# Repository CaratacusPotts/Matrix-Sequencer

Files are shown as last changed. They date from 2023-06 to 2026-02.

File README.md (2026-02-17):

# Matrix-Sequencer
**Stand Alone Midi Sequencer**, for immediate visual interaction with hardware synthesizers

## What
Midi sequencer designed to be easy to modify for beginners, and low cost to make.
Based on Arduino.

Operates in:
- Loop Mode
- Song Mode
- Conductor Mode

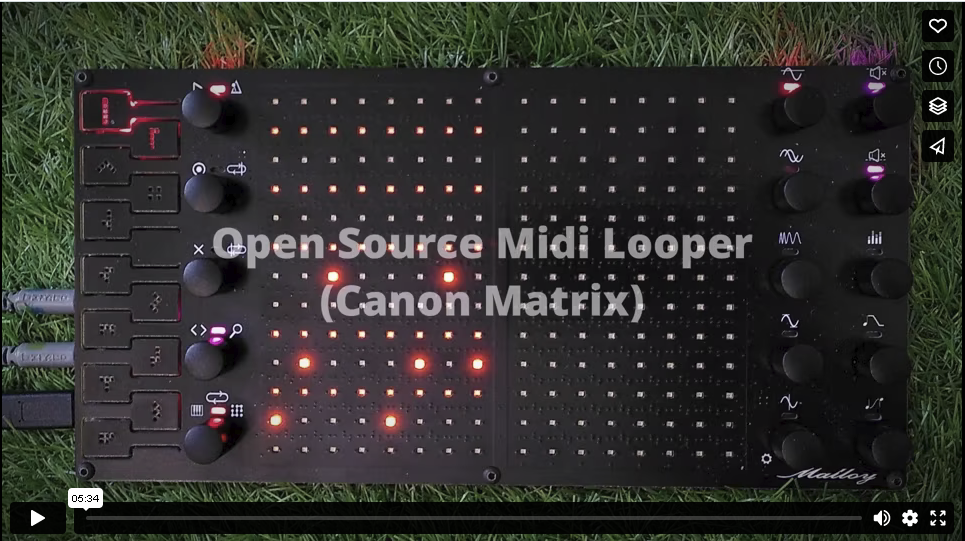
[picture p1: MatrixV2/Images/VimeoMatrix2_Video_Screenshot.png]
Video Thumbnail (https://www.youtube.com/watch?v=TjFpd8f3n0o)


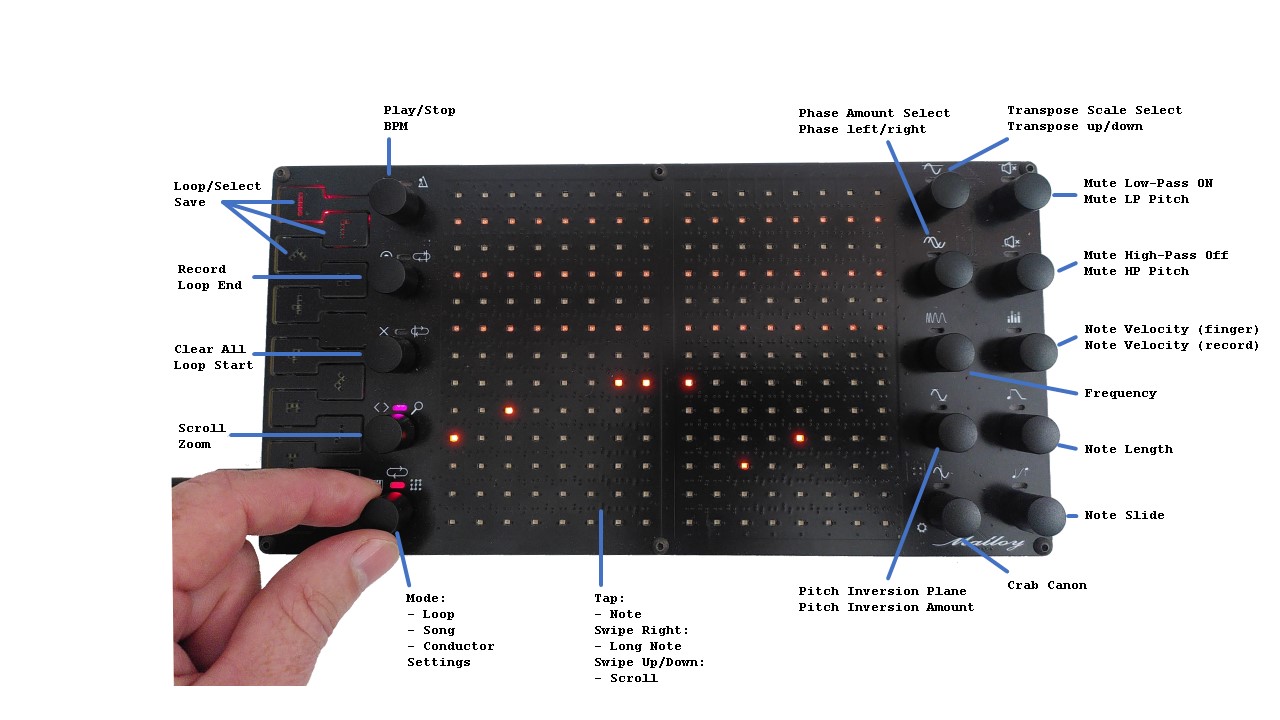
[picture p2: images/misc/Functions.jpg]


### Basic Functions (left row):
- Start/Stop: Play using internal clock or external midi clock
- BPM change using encoder
- Loop Start and End points via encoder
- Record:
  - Overtop: using Encoder button
  - On-Play: holding foot pedal, recording starts when first note played. Recording stops with foot off pedal. Automatically cuts loop to nearest beat, so loops nice.
- Clear notes (via encoder button)

### Canon and Note Functions (right rows):
- Transpose (to scale, on/off beat, via encoder or key input)
- Phase (by multiples of loop, by amount in steps)
- Frequency (compress note sequence in time, in fractions of current loop length)
- Mirror Notes Pitch (with a user defined mirror plane, reflect notes in pitch axis)
- Mirror Notes Loop (with a user defined mirror plane, reflect notes in time)
- Note Cutofff Filter (mute notes like a LPF or HPF)
- Note Velocity (use finger to draw note velocity or encoder)
- Note Duration (use encoder to increase or decrease all note lengths)

### Additional Features:
- 256 events (not bound by bars or specific steps)
- Polyphonic
- Intuitive scales

## [Specifications / Information Matrix V2 (encoder model)](MatrixV2/README.md)
## [Specifications / Information Matrix V1](MatrixV1/README.md)
## [Specifications / Informatoin Inline (simple midi looper)](Inline/README.md)

## Why
### Hardware synthesizer problem:

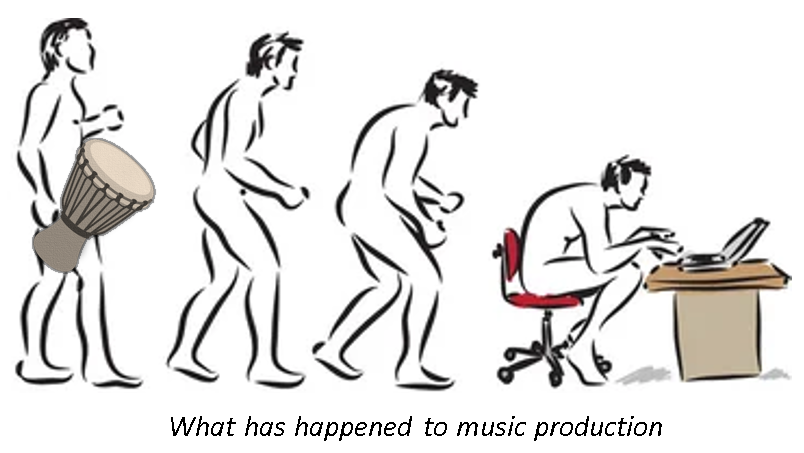
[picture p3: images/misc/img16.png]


Electronic music possesses both its greatest asset and its greatest drawback: the unparalleled flexibility it offers in sound creation. It's simple to purchase a laptop, load your favourite DAW software, and then to wake up, after you have nodded off to a loop running endlessly in your headphones. Perhaps you may get lucky, and a fortuitous accidental mouse click during your slumber may result in a masterpiece. However, it is more probable that your music will end up sounding sterile.

Hardware synthesizers currently provide immediacy, tangibility, reliability and lack of spontaneous OS updates, that PC's cannot provide.  But without expensive hardware, the only way to quickly layer sounds is to use built in key-holds playing standard arpeggios that steadily erode their beauty through endless repetition of the same up/down sequences.

Goal was to:
- make an interface that allows for quick note controller access, with immediate visual and tactile feedback - with a nod to the Reason Matrix
- Keep cost low.  There are solutions already that do similar things, but start at £650 upwards. 
- Enhance workflow and notation in areas that typically do not get attention, that have a meaningful impact of the quality of music, such as instant: 
  - Transposing in key
  - Phasing
  - High-pass and Low-pass velocity muting
  - Canon functions in key (Crab, Inversion, Reversing etc)
  - Hardware agnostic 303 style accents and glides
  - Velocity and length control
- Composer mode, allowing the user to play a midi keyboard, and to be able to select which fingers play which synthesizer (for example: left pinky plays bass, middle finger lead, first 3 fingers strings etc)
- Record mode, where it starts the recording only when you play, and stops the recording and automatically trims length when you remove you foot.  This allows seemless live looping.
- Loops that are not bound by 16,32 or 64 steps.  But is only bound by number of events.  In the current state, this is 255 events, over a 32bit length of steps (which at low tempo could be a 10 min loop)
- Scale not chosen by archaic and unrelatable names.  Notes (key) chosen by just selecting which white and black note you want it to stay on - yes, that simple.  (Does not currently handle option to change base notes if going up or down like in a some melodic minor scales - to be added) 
- Open source and easy to modify for non-programmers to allow people to add features and tweak to their setup.  I really tried to avoid the use of pointers, classes, libraries etc, as I wanted this to be software that anyone could modify - worts and all (I failed on the Midi Library - need remove this at some point)
- Fit into existing setups without changing anything (inline).
- Assemble at home with basic SMD tools, and a 3D printer.

## Contents of the repository

I have tried to include everything I created on this project.

Please note: There are some schematic errors which required minor board mods!!  I have not got around to updating the PCB files.  Please see notes in folders for each item.

Files are for:
- Matrix (second one - with encoders built in)
- Inline looper
- Inline controller
- Matrix (first one - with not encoders)

Each folder contains:
- PCB schematics
- PCB Kicad files
- Arduino Code
- Azoteq touch files
- CAD files (plastic)
- BOM (mostly mouser parts)

#### Numbering style is me having fun..  

We really need to move to a base-12 system.  So so much better.  This is my base-12 numbering, using the super cool Pentomino. See https://en.wikipedia.org/wiki/Pentomino  (thank you Arthur C Clake for enlightening me)

This is my sequence below.  Using the beauty of base 12, like in music there are those lovely 4x3's.  You can see the pattern repeating and growing in complexity (5 is a slight mod of one, 6 of 2 and so on.  9 slight mod of 5, 10 of 6 and so on).  Tried to not have the shapes the same as western numbers.

More info here: [PENTOMINO](Pentomino/INFORMATION.md)

I also wanted the first numbers to grow dimensionally 1 side, 2 side, 3 side (also shown as triangle), 4 side (Pentomino cross is shown as a negative, as it looks better - and makes a square :-) ). 
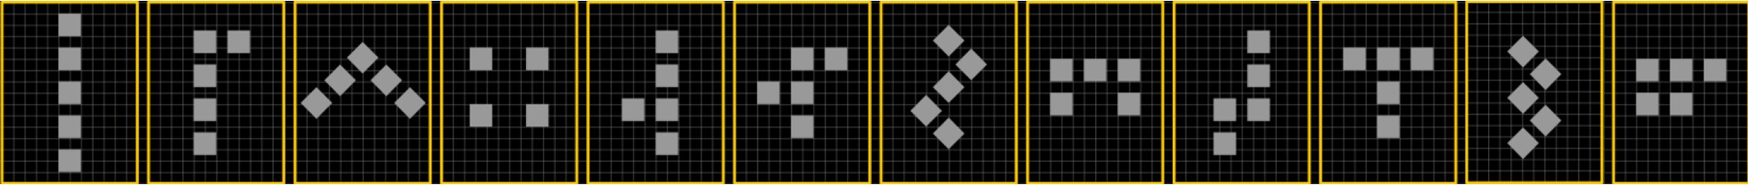
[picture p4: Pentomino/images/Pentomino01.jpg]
Pentomino01


## Photos

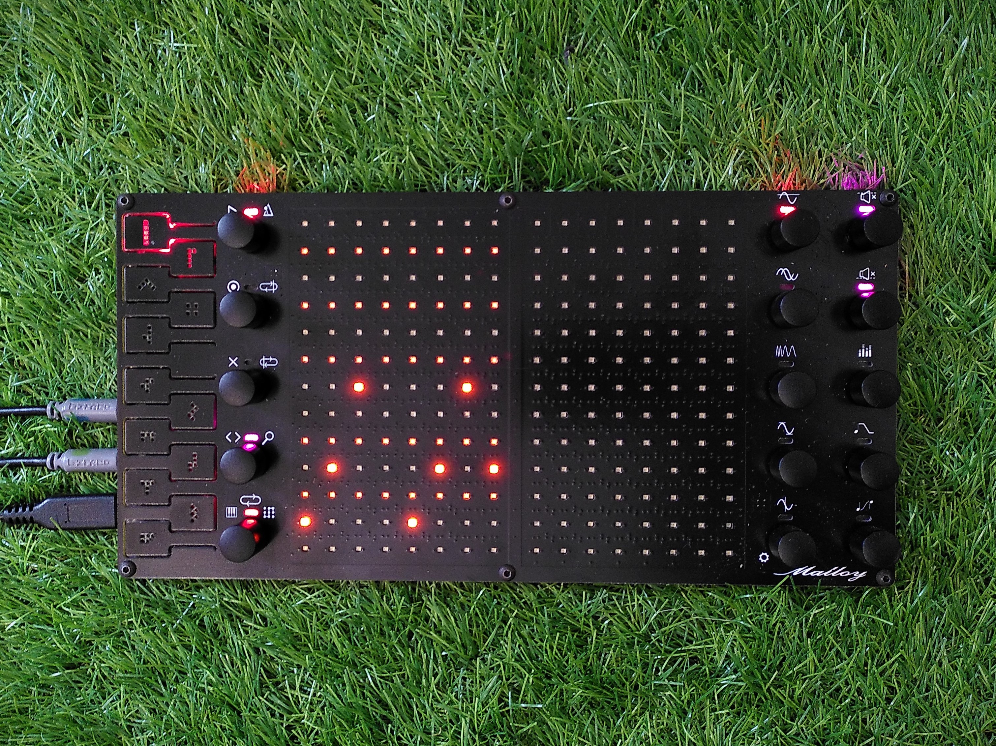
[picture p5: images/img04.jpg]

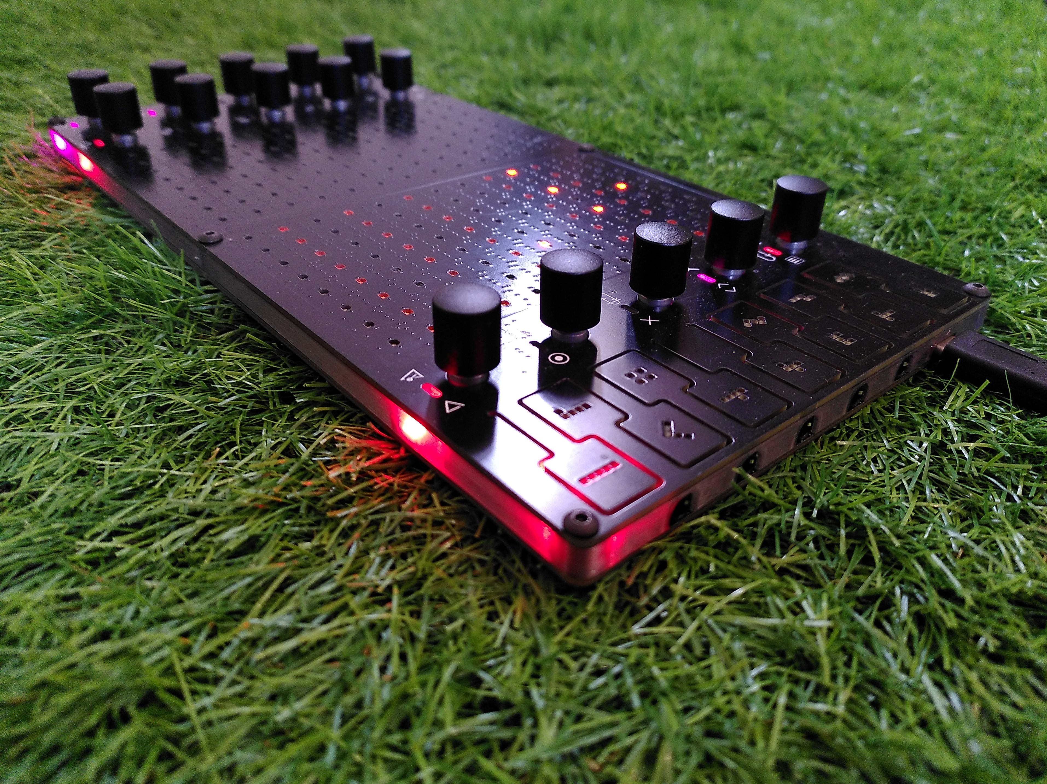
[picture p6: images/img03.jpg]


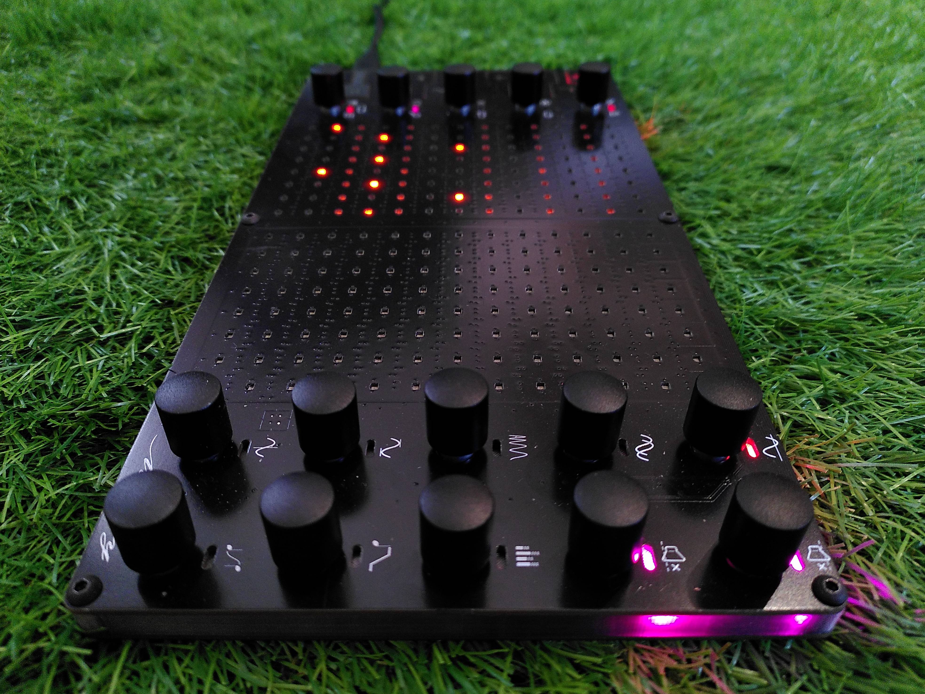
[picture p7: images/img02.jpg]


# Other Verions

## First Verison


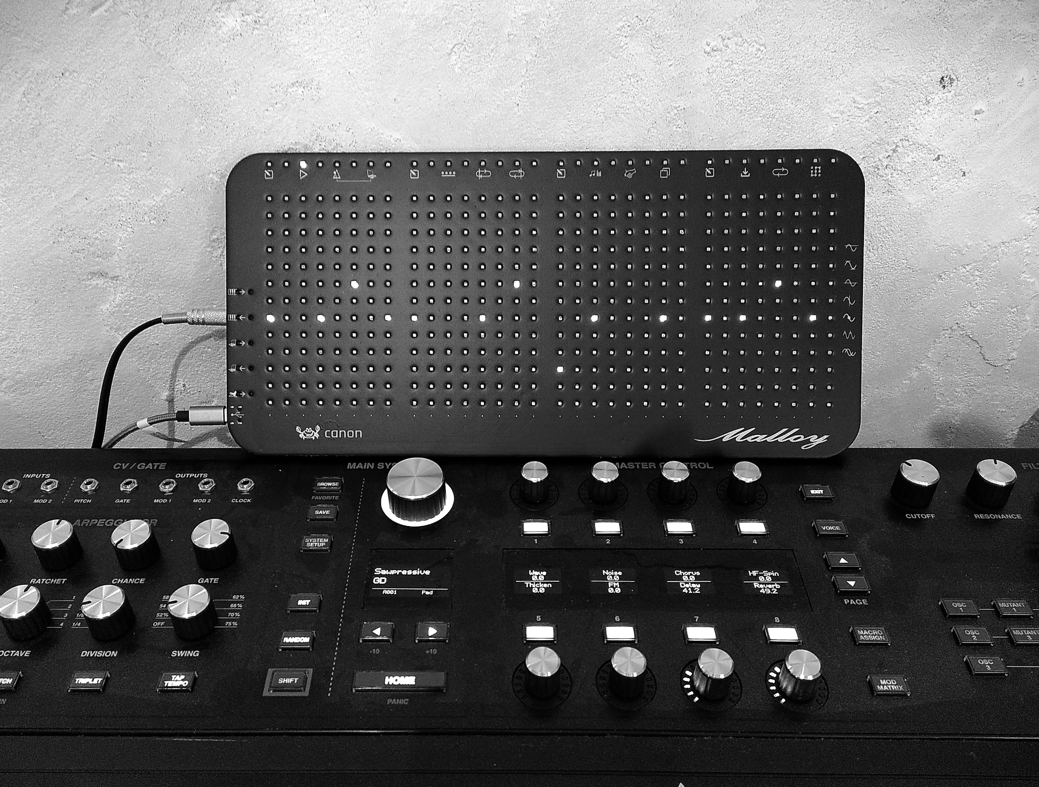
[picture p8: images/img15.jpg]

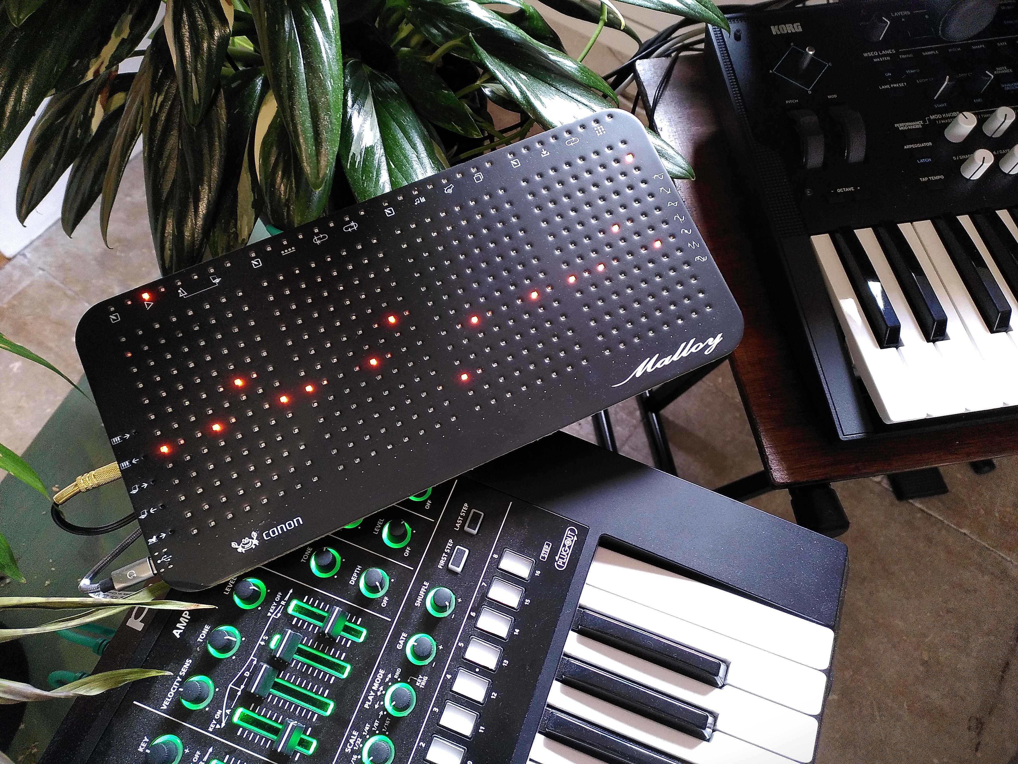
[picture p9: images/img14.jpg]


## Inline Midi 
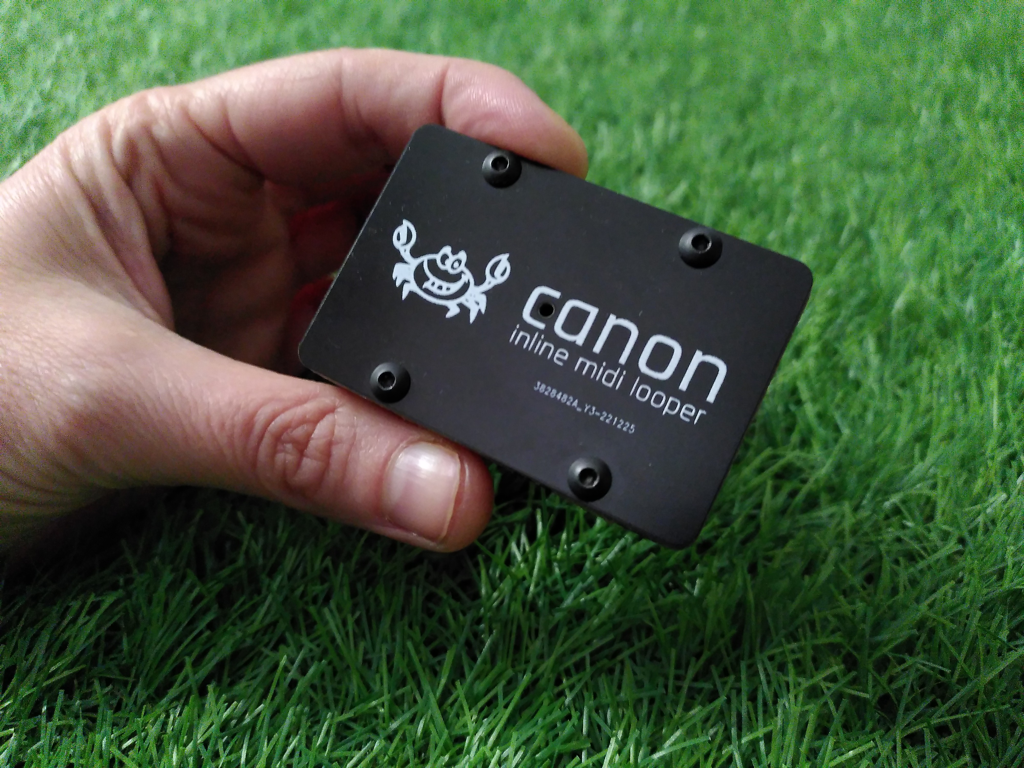
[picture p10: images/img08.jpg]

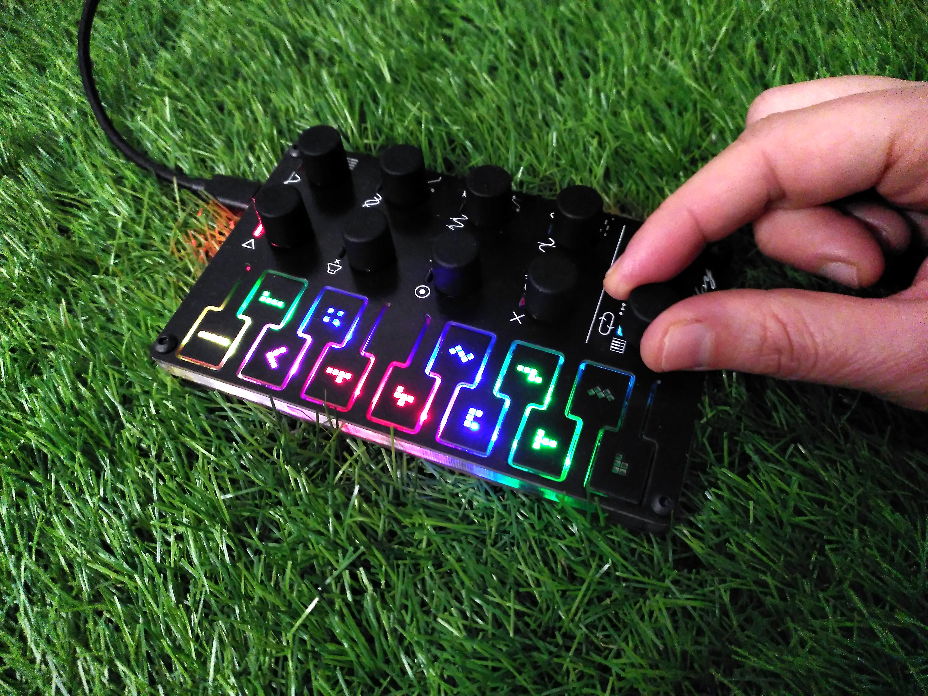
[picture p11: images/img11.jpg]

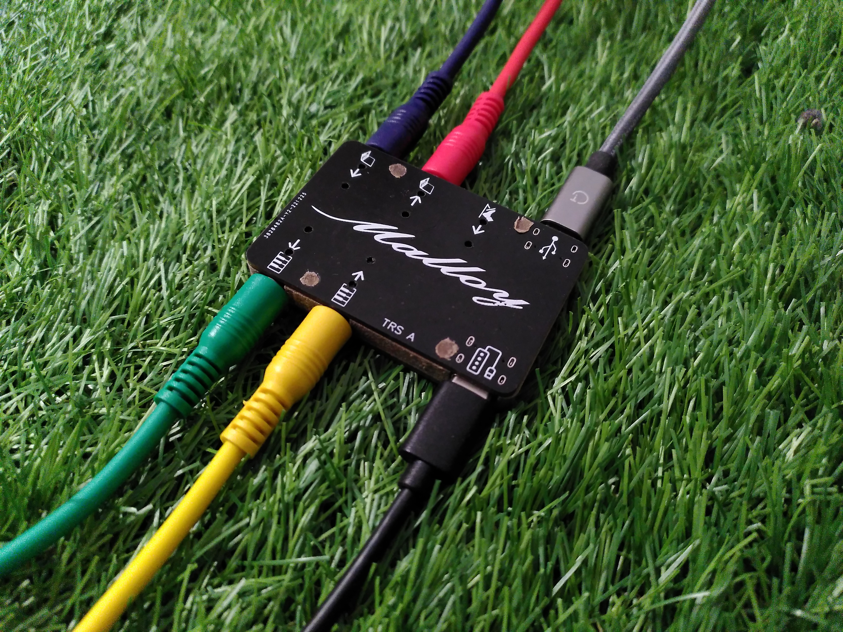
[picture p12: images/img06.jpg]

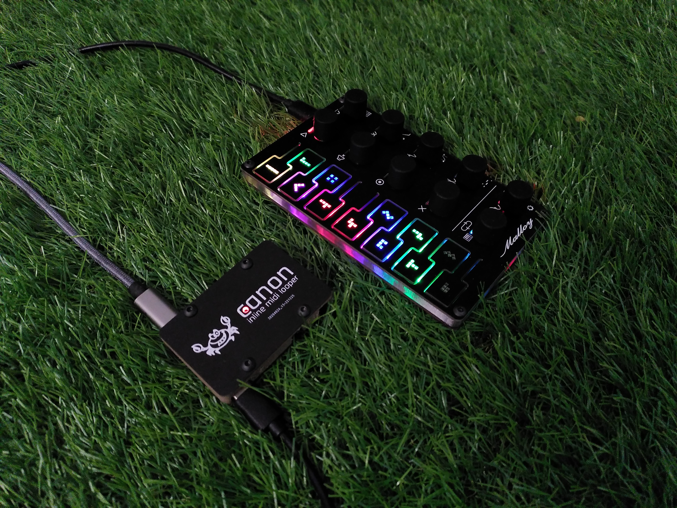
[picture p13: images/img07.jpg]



## Who
My name is Chris Malloy.  I developed the Hoverbike back in 2006.  For the last 10 years, my fantastic team and I have built a sucessful company that makes large heavy lift unmanned vehicles (company: Malloy Aeronautics www.malloyaeronautics.com )

I needed a break from that type of engineering, so whilst still helping the company, I have spent the last year finding time to work on this, and de-bug and have lots of fun playing on my gear.
If you want to listen to some very novice music made using this Matrix seqencer, see:
https://soundcloud.com/c-malloy

A Vimeo channel with a video of an earlier version of the Matrix
Version1 Sequencer (https://vimeo.com/770474252)

All the best

Chris

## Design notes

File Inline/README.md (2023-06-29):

## PLEASE NOTE:
This is a low TRL device, and as such, please see known issues below.

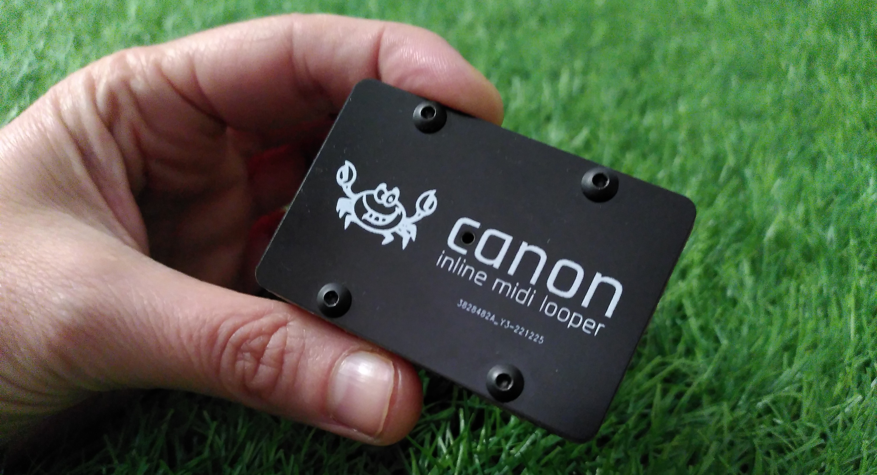
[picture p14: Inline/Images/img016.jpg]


## Overview
### Inputs and Outputs
- USB C to power and program
- USB C to connect to Controller
- 4x Midi TRS type A
  - Midi out to Synth
  - Midi in from Synth
  - Midi in from Computer/Master Clock
  - Midi out to computer/other
- 1x Trigger (3.5mm type) jack for pedal etc.

### Electronics
- Based on Adafruit ItsyBitsy MO Express https://www.adafruit.com/product/3727
- Processor: ATSAMD21 Cortex M0 processor running at 48 MHz
- External Memory: EEPROM 512k I2C
- 24 pin I/O Expander: PCAL6524HEAZ 
- Leds for indication: IN-PI55TATPRPGPB 
- Encoders, LDO power, Caps, Resistors etc

### Controls

- The controller works the same as the Matrix V2.
- This was an eariler version, that I used to experiment and debug the concept.
- THe Controller board needs some work, but the Inline Board (stand alone MIDI looper) is ready to go, and works quite well.

## Issues

### SCHEMATIC

### PCB

### CAD

### CODE

laylout
laylout
laylout
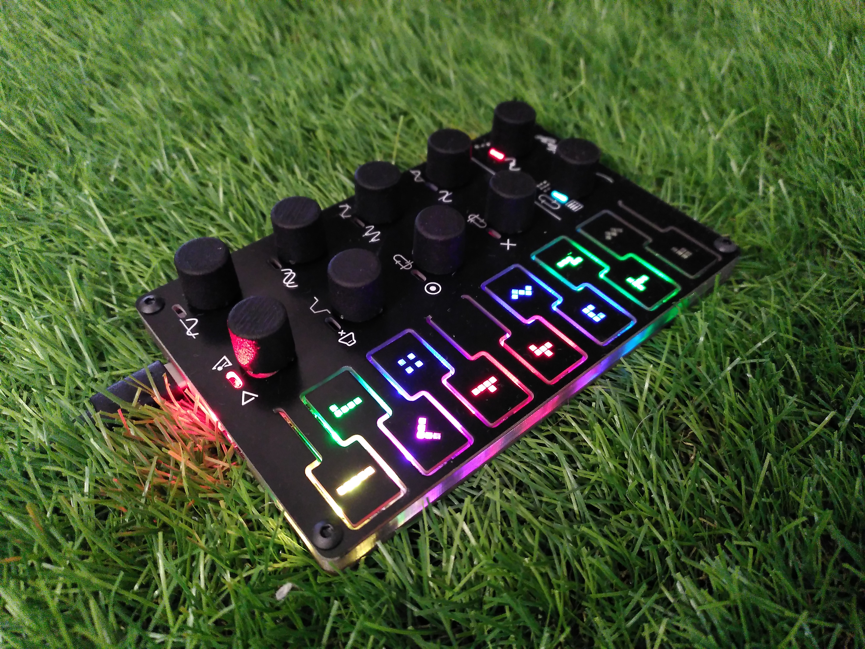
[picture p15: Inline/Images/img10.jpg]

laylout

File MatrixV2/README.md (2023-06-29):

## PLEASE NOTE:
This is a low TRL device, and as such, please see known issues below.

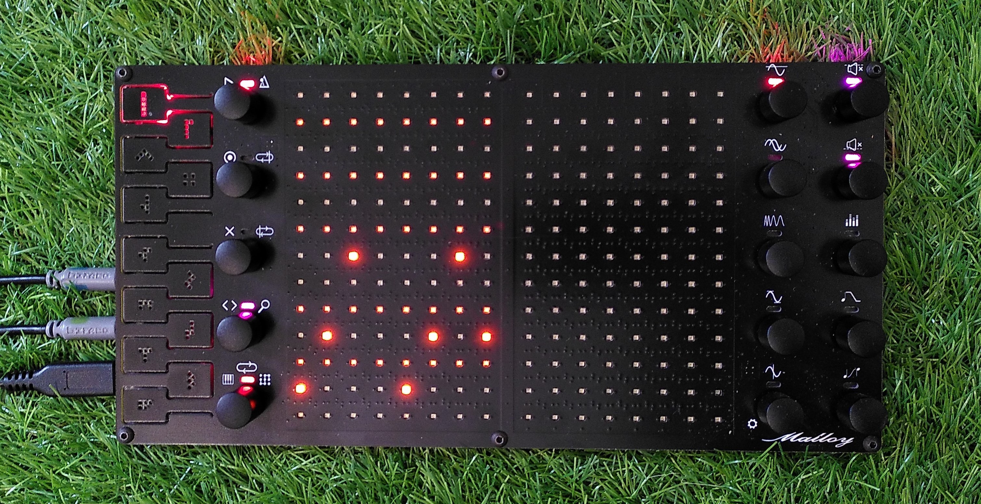
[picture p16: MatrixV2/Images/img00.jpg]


## Overview
### Inputs and Outputs
- USB C to power and program
- 4x Midi TRS type A
  - Midi out to Synth
  - Midi in from Synth
  - Midi in from Computer/Master Clock
  - Midi out to computer/other
- 1x Trigger (3.5mm type) jack for pedal etc.

### Electronics
- Based on Adafruit ItsyBitsy MO Express https://www.adafruit.com/product/3727
- Processor: ATSAMD21 Cortex M0 processor running at 48 MHz
- External Memory: EEPROM 512k I2C
- Touch: 2x Azoteq multitouch QS550 I2C
- 24 pin I/O Expander: 2x PCAL6524HEAZ 
- Led Latch: 2x CAT4016HV6G
- Leds for display: APTR3216SECK and RGB Leds for indication: IN-PI55TATPRPGPB 
- Encoders, LDO power, Caps, Resistors etc

### Controls

Buttons 1-12.  
- Used for saving (long press) loop
- Loading loop or song based on mode you are in (tap new number)
- Mute all notes (tap the same loop number).
- Also used to see scale, by holding the transpose button, you can select which notes you want the tranpose and other function to keep your pattern to.
- Play Notes
Encoders and Encoder Buttons (working down in columns - from left)
- Play/BPM
  - Click:  Start/Stop
  - Turn:  BPM
  - Click and Turn: Turn sync off/on
- Record/Loop End
  - Click: Record notes played in via midi, over top of current loop
  - Turn:  Adjust loop end point
- Clear/Loop Start
  - Click: Clear all notes
  - Turn: Adjust loop start point
- Scroll/Zoom
  - Turn: Scroll screen left/right
  - Press and Turn: Zoom in/out (by amount in steps-per-beat)
- Mode:
  - Turn: Left=Conductor Mode, Middle=Loop Mode, Right=Song Mode
    - Conductor Mode: See more information below
    - Loop Mode: Play loop continuously, based on internal BPM or external MIDI sync
    - Song Mode: See more information below
- Transpose:
  - Click: Active remote transpose.  This allows keyboard MIDI input to transpose note
  - Click and Hold: Set scale for tranpose, using number buttons (layed out as paino keys) or MIDI keyboard input.  
  - Turn: Transpose up/down
  - NOTE: Tranpose will try and shift notes onto the selected note only.
- Phase:
  - Click: Active phase.  This will phase shift the loop based on the number of times the loop has played
  - Click and Turn: Adjust the phase amount (negative or positive)
  - Turn: Manually phase shift notes
- Frequency
  - Turn: Change how fast the notes are played (*2 or /2 of current notes)
- Y-Mod Notes:
  - Turn: Reflect notes progressively about a defined axis
  - Click and Turn: Adjust where the reflection axis is (notes will be progressively reflected about this point)
- X-Mod Notes:
  - Turn: Reflect notes progressively about a defined axis
  - Click and Turn: Adjust where the reflection axis is (notes will be progressively reflected about this point)
- Mute LPF:
  - Click: Turn on.  All notes below threshold will play
  - Turn: Left sets threshold down in pitch.  Up goes up.
- Mute HPF:
  - Click: Turn on.  All notes above threshold will play
  - Turn: Left sets threshold down in pitch.  Up goes up.  
- Velocity:
  - Click: Use finger to draw note velocity
  - Turn: When playing, if you turn, this will record the velocity for one loop.
- Swing:
  - Not implemented yet.

 ### Loop Mode
 Play notes set on screen in continuous loop
 - x-axis (horizontal) is time
 - y-axis (vertical) is pitch
 - Half-lit horizontal lines on screen are the 'black' notes on a paino.
Just tap on screen to set notes to play.
Fully polyphonic.  No limit, other than processing time (huge amounts of notes in parallel 'might' create audiable lag)
Adjust loop length and other parameters via the knobs.
- Long notes (tie):  Tap where you want the start of the note, and then drag your finger (without lifting your finger) to the end of where you want the note.  To shorten the note, just tap where you want it to end.
- Swipe up or down to see notes outside of screen view
- Use the zoom in/out knob to create shorter or longer notes
Note: Timing is quantized.  The start and end of notes are not based on time - but fractions of a beat - based on the MIDI divisions of 24/beat.  This means you can only zoom in so far. (12 steps-per-beat, as we need 1 step for on, and 1 step for off, which makes 24)

 ### Song Mode
 Play multiple saved loops in a sequence, that is then loops
 - x-axis (horizontal) is the sequence of loops
 - y-axis (vertical) is the saved loop number
 - Loop End Knob sets end point (loops at this point)
Just tap on screen to set the loop number for when it will play.  For instance: if you want loop pattern 2 to play first, then 1, then 3 and 3 - tap (from bottom left corner) Col 1/Row 2, Col 2/Row 1, Col 3/Row 3, Col 4/Row 3.  Then set the vertical bar on the last loop (col 4 in this case)

### Composer Mode
Allows you to play multiple MIDI instruments at once, using different fingers (this is not a keyboard split)
For instance, if you want your left finger of your left hand to play notes on say a bass synth, your middle finger to play another synth, 3 fingers from the left hand a pad on another synth, and the rest of your fingers another, you can.
How it works:
- Everytime a note is pressed, the program looks up to see which note held down is 1st, 2nd, 3rd and 4th - starting from the lowest note on the keyboard
- You assign these note 'fingers' (1,2,3,4) to a MIDI out.
- There is a delay of less than one step (1/24th of a beat), to allow for chords being played, and fingers not de-pressing at the same time - this way you don't get jumps if transposing a sequence on another machine
- You can also assign 'all' through.  This means all notes you play go to that synth.

### [Schematic and PCB files - KiCAD](PCB)

### [CODE - Arduino](CODE)

### [CAD - Solidworks](CAD)

### [Programing Micro](Atmel)

### [Programing Touch](Azoteq_Touch)

## Issues
There are a few bugs and pooly written code.  See Code and PCB info files for known issues.

laylout
laylout
laylout
laylout

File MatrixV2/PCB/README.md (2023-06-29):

These files were created in Ki-cad.
Some of the pads are custom and need the footprints tweaking.
On the lower board (base), I don't recall any errors
On the upper board, I messed up on the PNP mosfet footprints(?), and the pins are wrong.  CHECK!!!, otherwise you will be doing what I did on this board and inverting and rotating the mosfets to get solder them.  Pain.

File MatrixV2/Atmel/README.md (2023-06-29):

# Programing the microcontroller.

## If the microncontoller already has the Arduino bootloader on it:

(using Arduino IDE), plug board into computer and use for board:
- Adafruit ItsyBitsy M0 Express (SAMD21)
- Don't forget to install libraries (sorry - I should get rid of libraries, as having them as dependencies sucks):
  - MIDI (https://github.com/FortySevenEffects/arduino_midi_library)
  - Wire (standard Arduino library)
  - FastLED for single wire LEDS (https://github.com/FastLED/FastLED)

## If you need to put the bootloader on to the microcontroller (new/fresh microcontroller)

Using MICROCHIP STUDIO software:
- Purchase a: ATATMEL-ICE-PCBA (its the cheapest I could find) Farnell: 2407171
- Connect to the following wires (see 'Connecting to an SWD Target' on page 22 in the ATMEL ICE datasheet for the ICE pins)
  - SWDIO
  - SWCLK
  - RESET
  - GND
  - 3.3V
- Open and go to tools - Device Programming
- Follow this guide: https://learn.adafruit.com/how-to-program-samd-bootloaders/programming-the-bootloader-with-atmel-studio
- I have put the adafruit Itsybitsy bootloader in this directory, if you need it
  - Happy Days.

Further Information:
- To add or shift the serial ports to other pins see:
  - https://learn.adafruit.com/using-atsamd21-sercom-to-add-more-spi-i2c-serial-ports/creating-a-new-serial
  - https://docs.arduino.cc/tutorials/communication/SamdSercom
- https://docs.arduino.cc/hardware/mkr-zero
- Bootloader https://github.com/adafruit/uf2-samdx1/releases
- Programing with bootloaders https://learn.adafruit.com/how-to-program-samd-bootloaders/programming-the-bootloader-with-atmel-studio

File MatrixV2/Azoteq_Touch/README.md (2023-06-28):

The board uses Azoteq chips for the touch (I did not get my custom touch working well enough - so was lazy and used the Azoteq.  Should move away from this, and just use a microcontroller...
Anyway.  You will need to program them. :-(  I would advise reading their manuals and adjusting the sensitivity better than I did..

Programming the touch needs to be done using an Azoteq CT-210 programmer (the one they specify for the Azoteq chip I am using)

- You can either use the hex or flash to program.
- You'll need to program via the pads on the PCB (check the schematic to see pinouts)
- Read the instructions to program in the Azoteq pdf: AZD087 – IQS5xx-B000 Setup and User Guide: https://www.azoteq.com/images/stories/pdf/AZD087%20-%20IQS5xx-B000%20Setup%20and%20User%20Guide.pdf

It would be a good idea to view the touch live via the I2C before programing to get a better idea as to what is going on with the touch.  To do this you will need to borrow the A4 port and write a relay code, so you can send commands (sorry, should have put the correct ports on the board)
On that note:  It would be a very good idea to mod the board to have the programing ports better available, as it was annoying having to solder and de-solder caps, to get comms on the chips working - as you'll need to modify their I2C address

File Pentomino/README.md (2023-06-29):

# Pentomino

I first discovered this when reading Arthur C. Clarke's 1975 novel Imperial Earth
After reading about Pentomino's on [wiki](https://en.wikipedia.org/wiki/Pentomino) I decided to make it more visually interesting, and to ensure the first 4 numbers represented and increase in sides (Line, 2 Sides, Triange, Square).

So what I have tried to do is to work with the base-12, and the 3x4 (and 3&4 are super interesting in music, from rhythm to harmonics - which you can't really get from a base-10).  We really need to move to a base-12 system.  So so much better.  

The 4 side is the Pentomino cross, but is shown as a negative, as it looks better, does not look like an addition or multiplication sign - and makes a square :-).

You can see the pattern repeating and growing in complexity (5 is a slight mod of one, 6 of 2 and so on.  9 slight mod of 5, 10 of 6 and so on).  Tried to not have the shapes the same as existing numbers.

Pentomino01

You can see the evolution and repetition better here:

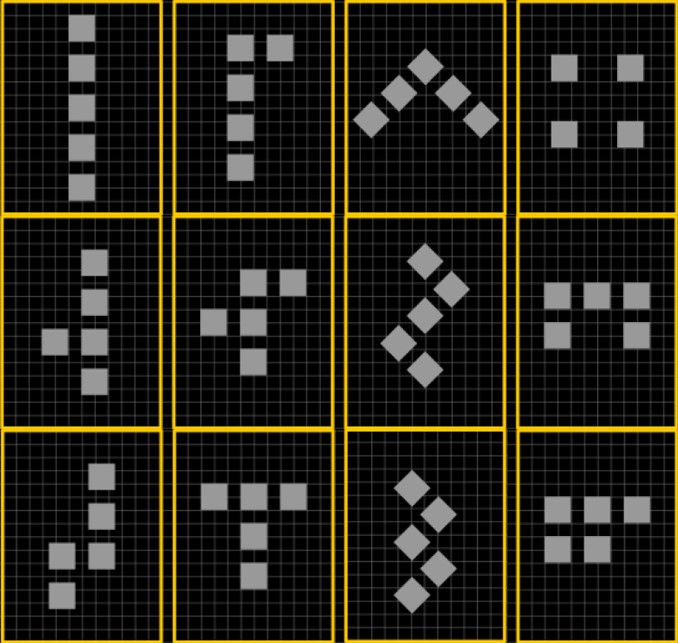
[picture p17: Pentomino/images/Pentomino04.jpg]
Pentomino04


And in a more 'normal' writing

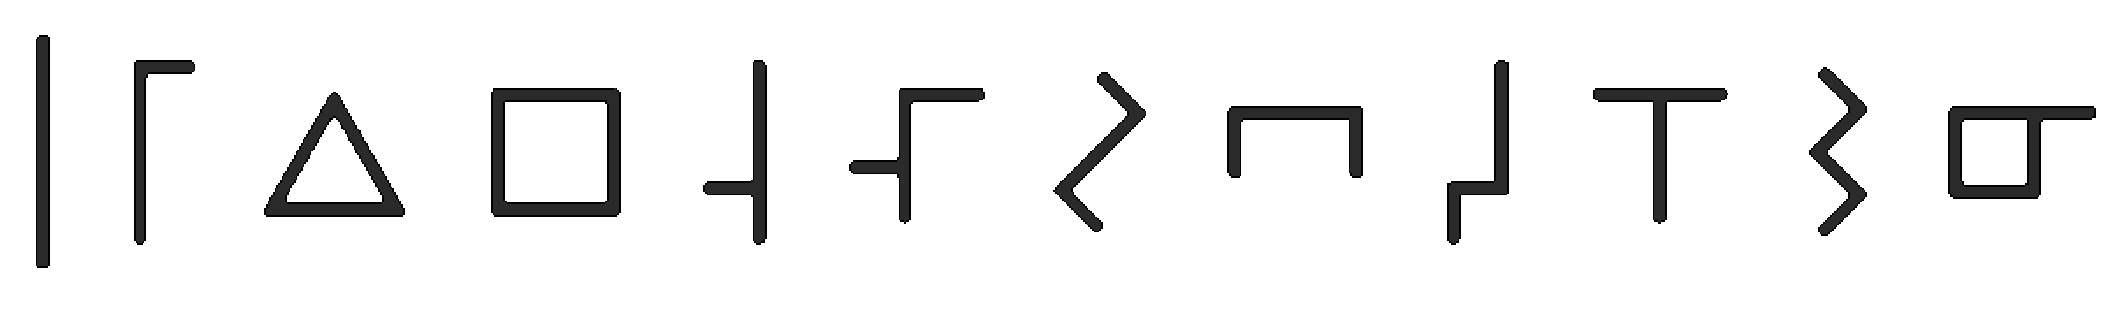
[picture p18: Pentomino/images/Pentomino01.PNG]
Pentomino04


I have some CAD files [here](Pentomino/CAD) (solidworks, dxf, step)

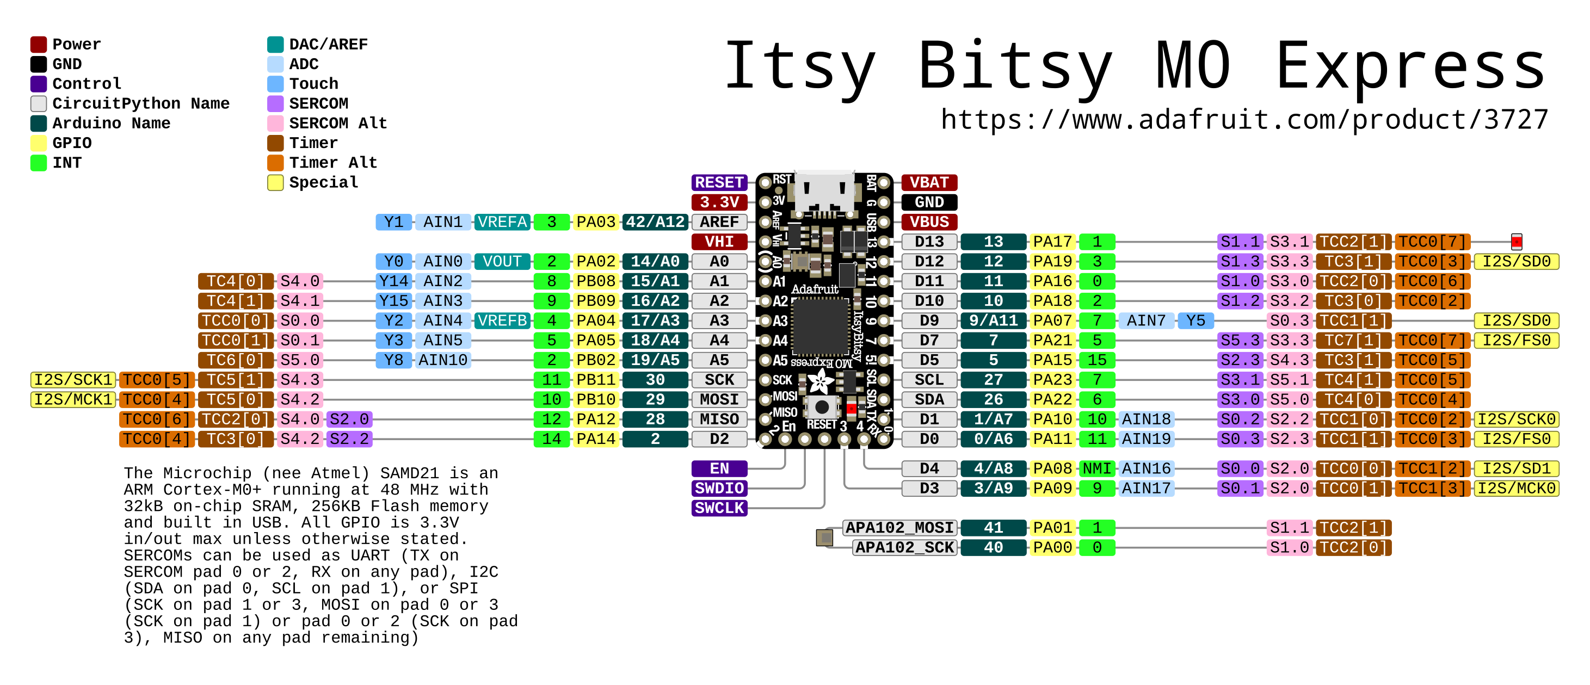
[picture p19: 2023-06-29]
MatrixV2/Atmel/adafruit_products_Adafruit_ItsyBitsy_M0_pinout.png

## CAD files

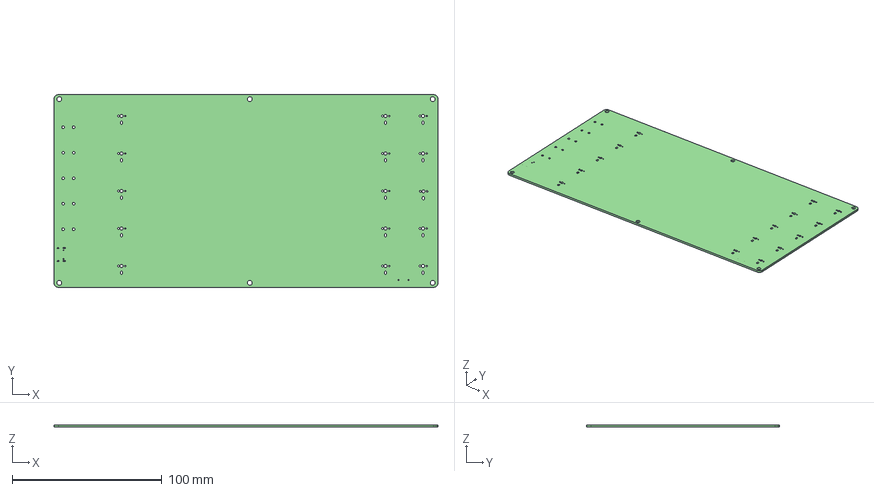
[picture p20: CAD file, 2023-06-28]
MatrixV2/PCB/Matrix_V2_Base/Matrix_V2_Base.step
256.0 x 128.5 x 1.60 mm

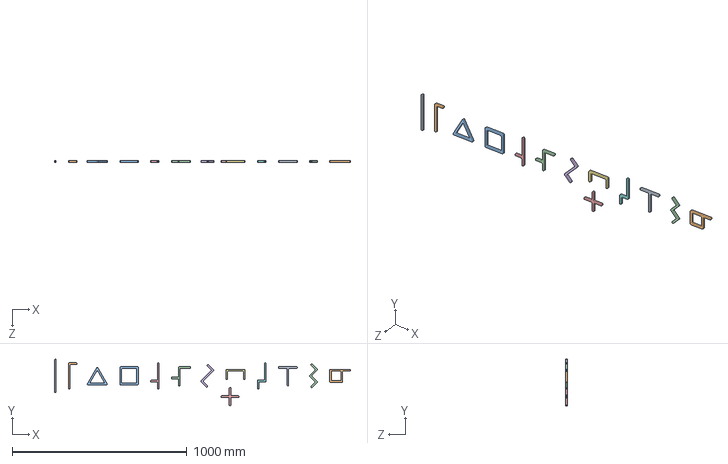
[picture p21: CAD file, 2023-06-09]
Pentomino/CAD/Pentomino_Slim.STEP
1695.9 x 266.6 x 10.0 mm

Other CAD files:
Pentomino/CAD/Pentomino_Squares.SLDPRT
Pentomino/CAD/Pentomino_Slim.DXF
Pentomino/CAD/Pentomino_Slim.SLDPRT
Pentomino/CAD/Pentomino_Squares.DXF

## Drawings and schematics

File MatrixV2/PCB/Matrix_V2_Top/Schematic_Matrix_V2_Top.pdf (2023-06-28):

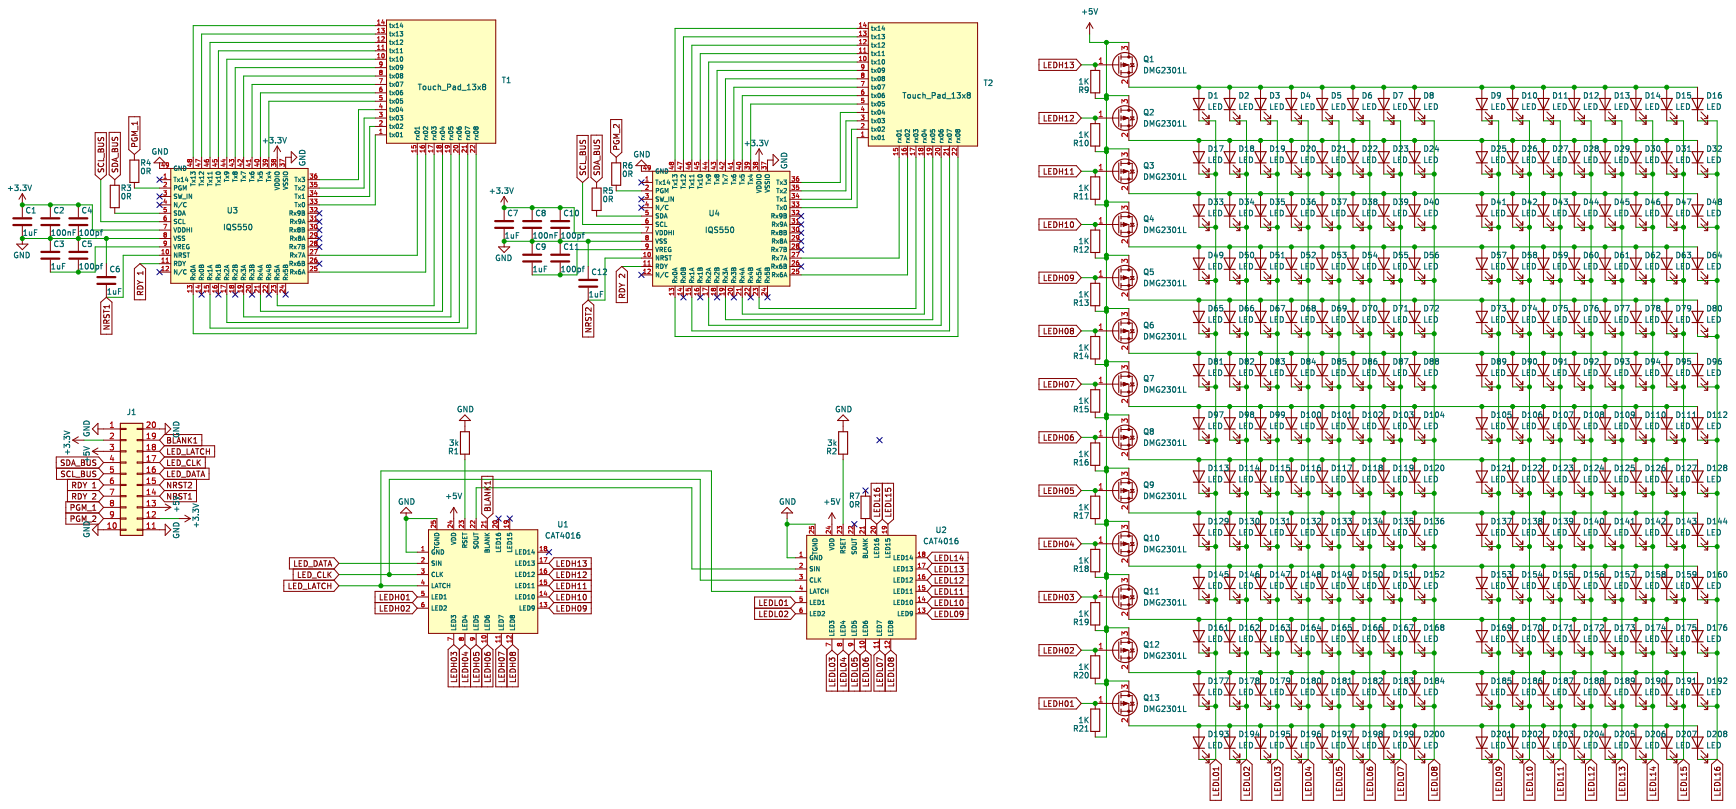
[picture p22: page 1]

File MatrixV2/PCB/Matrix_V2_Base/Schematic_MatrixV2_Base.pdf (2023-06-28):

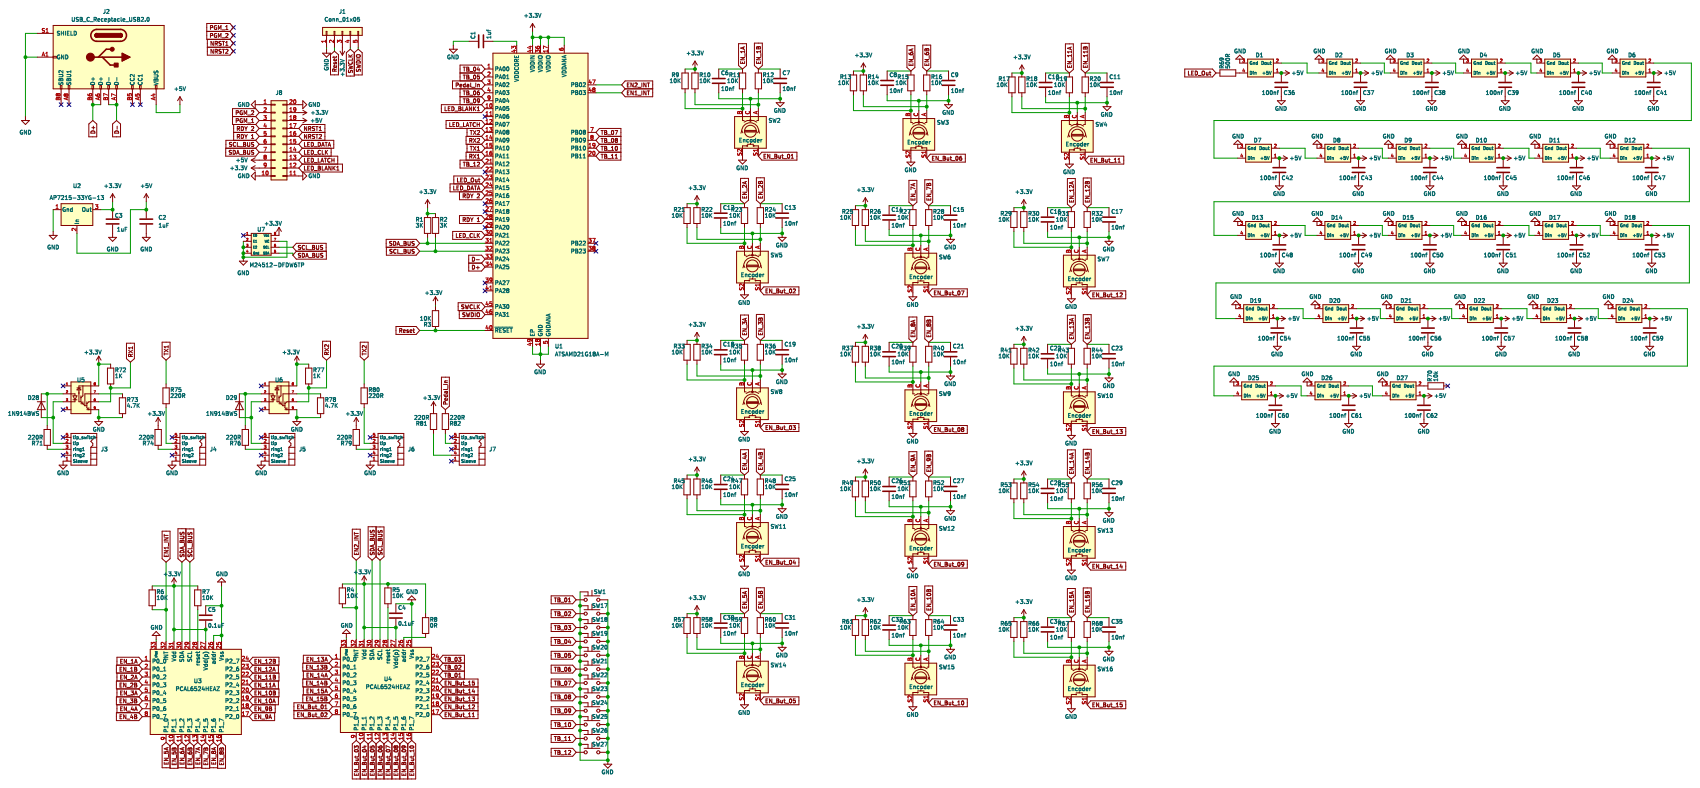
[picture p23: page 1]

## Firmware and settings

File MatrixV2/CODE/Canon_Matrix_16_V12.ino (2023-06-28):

#include "variables.h"

//

MIDI_CREATE_INSTANCE(HardwareSerial, Serial2, MIDI2);
MIDI_CREATE_INSTANCE(HardwareSerial, Serial1, MIDI);

//  INLINE CONTROLLER STUFF  *******************************************************
//  Uart Serial3 (&sercom1, 9, 8, SERCOM_RX_PAD_1, UART_TX_PAD_0);  // RX on D13 (SERCOM1.1)   TX on D11 (SERCOM1.0)  Using Arduino Zero: D11 = D8, D13=D9
//  void SERCOM1_Handler(){Serial3.IrqHandler();}
//  MIDI_CREATE_INSTANCE(HardwareSerial, Serial3, MIDI3);
// **********************************************************************************


void setup() 
{  
  pinMode(latchPin, OUTPUT); 
  pinMode(dataPin, OUTPUT);  
  pinMode(clockPin, OUTPUT);
  pinMode(RDY1pin, INPUT); 
  pinMode(RDY2pin, INPUT);  
//  pinMode(RDY3pin, INPUT); pinMode(RDY3pin, INPUT_PULLDOWN); 
//  pinMode(RDY4pin, INPUT);    pinMode(RDY4pin, INPUT_PULLDOWN); 
  pinMode(PedalInL, INPUT);  
  pinMode(LEDBlank, OUTPUT); //pinMode(LEDBlank, INPUT_PULLDOWN); 
  digitalWrite(LEDBlank, LOW); 

  
  Serial.begin(115200);  
//  Serial3.begin(115200);  

  Wire.begin();  
  Wire.setClock(800000);   
  
  MIDI.begin(MIDI_CHANNEL_OMNI);
  MIDI.turnThruOff();
  MIDI.setHandleNoteOn(noteIn);                                // Tells the Midi Library to call NoteIn when a NOTE ON command is received.
  MIDI.setHandleNoteOff(noteOffIn);                            // Tells the Midi Library to call NoteOffIn when a NOTE OFF command is received.
  MIDI.setHandleControlChange(ccIn);
  
  MIDI2.begin(MIDI_CHANNEL_OMNI);
  MIDI2.turnThruOff();    
  MIDI2.setHandleNoteOn(noteIn);                                // Tells the Midi Library to call NoteIn when a NOTE ON command is received.
  MIDI2.setHandleNoteOff(noteOffIn);                            // Tells the Midi Library to call NoteOffIn when a NOTE OFF command is received.
  MIDI2.setHandleControlChange(ccIn);
  
  // Assign pins 3 & 4 SERCOM functionality
  pinPeripheral(3, PIO_SERCOM_ALT);
  pinPeripheral(4, PIO_SERCOM_ALT);

  pinMode(36, INPUT); pinMode(19, INPUT);    // expander interupt pin
  pinMode(36, INPUT_PULLUP); pinMode(19, INPUT_PULLUP);  // expander interupt pin
  portExpanderConfig();
  getCurrentEncoderState();
  for(int i=3;i<12;i++)
  {
    int pin = tbList[i];
    pinMode(pin,INPUT); pinMode(pin, INPUT_PULLUP); // set as input
    bool v = digitalRead(pin);
    bitWrite(tbState,i,v);  // set to current state.
  }

  FastLED.addLeds<WS2812,ledOut,RGB>(leds,ledNum);
  FastLED.setBrightness(40);
      

  recordSwitchOff = digitalRead(PedalInL);     //  Setting the offState of the recordswitch on startup.
  recordSwitchLast = recordSwitchOff;           // Setting the last last as this one.

  uint8_t b[2];
  readEEPROM(0,b,1);
  if(b[0] != 68){loadDefaultValues();}
  loadSavedValues();
  
  for(int i=0; i<16; i++) 
  { 
    for(int p=noteMin; p<=noteMax; p++) {notesStepOff[i][p] = -1;} 
    conductorOut[i][0]=0; conductorOut[i][1]=0; conductorOut[i][2]=0; conductorOut[i][3]=0; conductorOut[i][4]=0; conductorOut[i][5]=0; 
  }
  
  initialiseNoteArray();
  ledClearArray();
  //prePattern();  
  nextEvent(Addr); nextEvent(Addr);
  
//  INLINE CONTROLLER STUFF  ******************************************************************************
/*
  // Check to see if touch screen available - if not disable touch screen and led.
  Wire.beginTransmission(112);
  byte screenAvailable = Wire.endTransmission();
  if(screenAvailable != 0)
  {
    touchScreen = false; ledScreen = false;startStop = true; loopStart();
    pinMode(RDY4pin, OUTPUT);
    digitalWrite(cdData, HIGH);  digitalWrite(dataPin, LOW); digitalWrite(RDY4pin, HIGH); 
  }

  pinPeripheral(11, PIO_SERCOM);
  pinPeripheral(13, PIO_SERCOM);
  
  MIDI3.begin(MIDI_CHANNEL_OMNI);
  MIDI3.turnThruOff();
  MIDI3.setHandleControlChange(ccIn);   

  checkForController(); // Check if Controller is present

*/
//  *******************************************************************************************************
   
  
  ledRefreshScreen();
  
  ledTimeLast = micros();    
  ledTurnOffKeys = micros();
  panelTimeLast = millis();    
  encoderTimeLast = millis();
        
  intClockuS = (1000000/(bpm/60))/24;   
}

void loop() 
{ 
  
  if(MIDI2.read())
  {
    switch(MIDI2.getType())
    {
      case midi::Clock :{if(clkSync){intClock();} if(clkSyncFree && !clkSync){clkSync=true;} } break;
      case midi::Start :{MIDI2.sendRealTime(MIDI_NAMESPACE::Start); startStop = true; if(!recording){loopStart();}} break;            
      case midi::Stop :{MIDI2.sendRealTime(MIDI_NAMESPACE::Stop); startStop = false; stepCount = 0; Addr = 0; loopStop();} break;
      default: break;
    }
  } 
  MIDI.read();  
//  MIDI3.read();
  
  unsigned long timeNow = micros();                                                 // Do clock timer

  if(!clkSync)
    {if(timeNow - clockTimeLast > intClockuS){clockTimeLast = timeNow; intClock();}}
  
  if(nextStep == stepCount) 
    {if(!mute && startStop){ playNote(nextStep);}} 

  if(micros() - ledTimeLast > ledTime)
  {
    //unsigned long delta = (timeNow-ledTimeLast) - ledTime;
    //if(delta > 700){Serial.println(delta);}
    ledTimeLast = micros(); updateLEDs();
  }                 // ****************  Update LED (frame) ********************** 
  if(timeNow > ledTurnOffKeys){ledTurnOffKeys = ledTurnOffKeys + 90000; digitalWrite(LEDBlank, HIGH);}  
  
  if(timeNow - panelTimeLast > touchTime)   // Read at 50mS interval.  For Touch Panel & Record Switch
  {
    panelTimeLast = timeNow; 
    if(touchScreen){checkTouch();}              // Check Touch Screen States
    recordSwitch();                             //  Check Record Switch State.
    for(int i=3; i<12; i++)                     // Check Touch Switches
    {
       bool v = digitalRead(tbList[i]);
       if(v != bitRead(tbState,i)){bitWrite(tbState,i,v); ccIn(channelIn, ccNum, 60+(i*4)+v);}
    }
  }  

  if(millis() - encoderTimeLast > 10);
  {
    if(!digitalRead(36)){readEncoders(1);}
    if(!digitalRead(19)){readEncoders(2);}    
  }

  playOffNote(stepCount);       // play end notes

  if(loopStartFlag)  // if someone hits play, while the loop in in the middle of a beat.  Wait for beat to play start.
  {
    int b = fmod(stepCount,24); // 24 because there is 24 steps per beat
    if(b == 0)
    {
      loopStartFlag = false;
      loopStart();
    }
  } 

  if(recordFlag)  // somebody has used the record switch to record
  {
    if(micros()- recordPedalTimeLast > 750000)
    {
      if(transposeActive){transposeState(2);} // tun off - just in case user forgot
      recordFlag = false; recordStart(); Serial.println(" Rec.. ");
    }
  }
  if(recCCNextPattern)  //  somebody has used the record switch to alternate pattern
  {
    if(micros() - recordPedalTimeLast > 600000)
      {
        recCCNextPattern = false;
        if(loopNum == 0){loopNum = 1;}else{loopNum = 0;} 
        loadLoopActive=true;
        Serial.print(" LoadLoop: ");Serial.println(loopNum);
      }
  }
  if(enRecLoopFlag != 0)
  {
    if(enRecLoopStartStep == stepCount) // has done one loop since knob moved..
    {
      enRecLoopFlag = 0; enRecLoopValue = 0; Serial.println("FlagOff"); 
    }
  }

  if(buttHoldFlag > -1  && Mode == 0)  // IF user is long pressing button.  Indicate time has passed with LED
  {
    if(millis() - buttActionTimeLast > 1000)
    {
      saveTheLoop(buttHoldFlag);     //Save Loop
      buttHoldFlag = -1;
    }
  }
        
  if(loadLoopActive)
  {
    loadLoopActive = false;
    int loopLast = loopNum;
    if(songMode)
    {     
      ++songStep; 
      if(songStep > songEndStep || songStep < songStartStep) {songStep = songStartStep;}  
      Serial.print(" SongStep: ");Serial.println(songStep);
      loopNum = songArray[songStep];
    }
    notesOffAll();
    if(loopNum < 0 || loopNum > 13){loopNum = 0;}
    if(loopNum != loopLast){loadTheLoop(loopNum);}   // no point in reloading the same loop.  
    Addr = 0;  
    nextEvent(Addr);
    if(loopMode){ledRefreshScreen();}
  }

  if(resetScreenFlag)
  {
    unsigned long timePast = millis() - resetScreenActionLast;
    if(timePast > 1200){resetScreenFlag=false; editSettings =0; ledRefreshScreen();}
  }
   
  if(Serial.available() > 0) {readSerial();}

}

void intClock()
{
  MIDI.sendRealTime(MIDI_NAMESPACE::Clock);
  if(startStop)
  {
    ++stepCount; 

    
    if(recordingStop){recordEnd(stepCount -1);}  // Finish off the recording after the foot pedal has deactivated.  
  
    if(stepCount == stepEnd && songMode)
      {loadLoopActive = true;}    
    if((stepCount > stepEnd && !recording))
      {loopEnd();}

    if(recording)   // Scroll screen
    {
      int stepsInWindow = stepsPerLED * nCols;                     // ie: 24 steps a beat.  If 4 notesPerBeat, then 32/4notesPerBeat = 8Beats.  8*24 = 192
      if(stepsInLoop >= stepsInWindow)  
      { 
        int wS = stepCount/stepsPerLED;
        if(wS < nCols){winXStepStart = 0;}
        else{winXStepStart = wS;}
        ledRefreshScreen();
      }
    }
    
    int noteStep = stepCount % stepsPerLED;
    if(conductorChange && noteStep){ conductorChange = false; conductorPlay(); }
    if(transposeFlag && noteStep){transposeFlag = false; offsetNotes(transposePitch);}    
  }
}
  
void loopEnd()  
{  
  stepCount = stepStart;                                // go back to begining (would be step 0, but as we can change the start step..                
  playOffNote(stepCount);       // play end notes
    
  if(phaseActive){stepCount = stepCount + phaseAmount;}
  
  Addr = 0; 
  nextEvent(Addr);
  if(nextStep < stepCount) // if the start point is after step 0 - advance the Addr marker till you find its on or after the stepStart step.
    {for(int i=0;i<255;i++) { nextEvent(Addr); if(nextStep >= stepCount){break;} }}
}

void loopStart()
{ 
  //Serial.println("loop start");
  stepCount = stepStart; songStep=0;
  playOffNote(stepCount);       // play end notes 
  
  mute = false;  
  winXStepStart = 0; 
  
  ledRefreshScreen();

  Addr = 0;  
  nextEvent(Addr); 
  if(nextStep == stepCount && !mute) {playNote(nextStep);} 
  enRecLoopFlag = 0;
}


void loopStop()
{ 
  notesOffAll();  
  enRecLoopFlag = 0;  
}


void checkForController()
{
  ccOutSerial3(102,channelIn);
  delay (10);
 // MIDI3.read();
}

void readSerial()
{
    byte b = Serial.available();
    char a[b];
    Serial.readBytes(a,b);
    byte num;
    if(b>4){num = ((a[1]-48)*10) + (a[2]-48);}
    switch (a[0])
    {
      case 'x':{ccIn(channelIn, 35, 1); ccIn(channelIn, 35, 0);} break;
      case 'n':{noteIn (channelIn, num, 100);} break;  // note in  
      case 'i':{channelIn = num; byte ch[] = {num}; writeEEPROM(globalMemStart+2,ch,1);Serial.print("Chan In:");Serial.println(channelIn);} break;   
      case 'o':{channelOut = num; byte ch[] = {num}; writeEEPROM(globalMemStart+1,ch,1);Serial.print("Chan Out:");Serial.println(channelOut);} break;   
      case 'p':{Serial.print("P, Play   Clksync:");Serial.println(clkSync);startStop = true; loopStart();} break; 
      case 't':{touchScreen = !touchScreen;Serial.print("T ");Serial.println(touchScreen); pinMode(RDY4pin, OUTPUT);}   break; // T Touch off/on
      case 'l':{ledScreen = !ledScreen;Serial.print("L "); Serial.println(ledScreen);} break;      // L LED off/on
      case 'r':{recOvertop();} break; 
      case 'R':{if(recording){ccIn(channelIn, 64, 0);} else{ccIn(channelIn, 64, 127);}} break; 
      case 'c':{transposeEditChord(num); transposeSaveChord();} break;
//      case '<':{canonPhaseNotes(-1);} break;
//      case '>':{canonPhaseNotes(1);} break;
    }
}

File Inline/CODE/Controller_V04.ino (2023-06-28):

// Controller for Canon Matrix
#include "variables.h"

MIDI_CREATE_INSTANCE(HardwareSerial, Serial1, MIDI);

void setup() 
{
  Serial.begin(115200);      
  Wire.begin();  
  Wire.setClock(1000000);      // try 100kHz bus first
  
  MIDI.begin(MIDI_CHANNEL_OMNI);
  MIDI.turnThruOff(); 

  MIDI.setHandleControlChange(ccIn);

//  lcd.init();
//  lcd.setCursor(0,0);
//  lcd.print("Boobs");
  
  portExpanderConfig();
  getCurrentEncoderState();
  pinMode(36, INPUT);   
  pinMode(36, INPUT_PULLUP);   

  pinMode(latchPin, OUTPUT);
  pinMode(dataPin, OUTPUT);  
  pinMode(clockPin, OUTPUT);
  int tbMap[] = {18,9,4,3,29,30,28,2,5,12,7,19}; for(int i=0; i<12; i++){pinMode(tbMap[i], INPUT); pinMode(tbMap[i], INPUT_PULLUP); }
  int enTbMap[] = {40,41,14,42,16,17}; for(int i=0; i<6; i++){pinMode(enTbMap[i], INPUT); pinMode(enTbMap[i], INPUT_PULLUP); }

  for(int i=0; i<22; i++){buttonState[i] = 0;}  // set button state to zero.
  for(int i=0; i<48; i++){ledState[i] = 0;}     // set LED array to zero
  for(int i=0; i<127; i++){ccOutputLast[i] = 0;}  // set debounce out to zero
    
  keyTimeLast = micros();
}

void loop() 
{
  MIDI.read(); 

  if(!digitalRead(36)){readEncoders();}
  
  unsigned long timeNow = micros(); 
  if(timeNow - keyTimeLast > 5000) {keyTimeLast = timeNow; calcButtons(); outputLed();}   // Read at 5mS interval
  
  if(Serial.available() > 0)  { readSerial(); }
}
